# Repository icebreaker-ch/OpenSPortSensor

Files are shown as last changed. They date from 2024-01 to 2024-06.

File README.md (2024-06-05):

# Welcome to OpenSPortSensor
Telemetry for *FrSky* RC Receivers using the **SPort** interface.

The main goals for this project were:
- Provide a software easy to adapt for your own sensors by implementing a simple interface
- Support different *Arduino* boards by using high level libraries for communication only
- Support Hardware- and Software-Serial interfaces
- Supply a set of standard sensors for e.g. voltage and current measurement

The Documentation for this project can be found in the [wiki](https://github.com/icebreaker-ch/OpenSPortSensor/wiki)

<p align="center">
  <table>
    <tr>
      <td align="center">
        <figure>
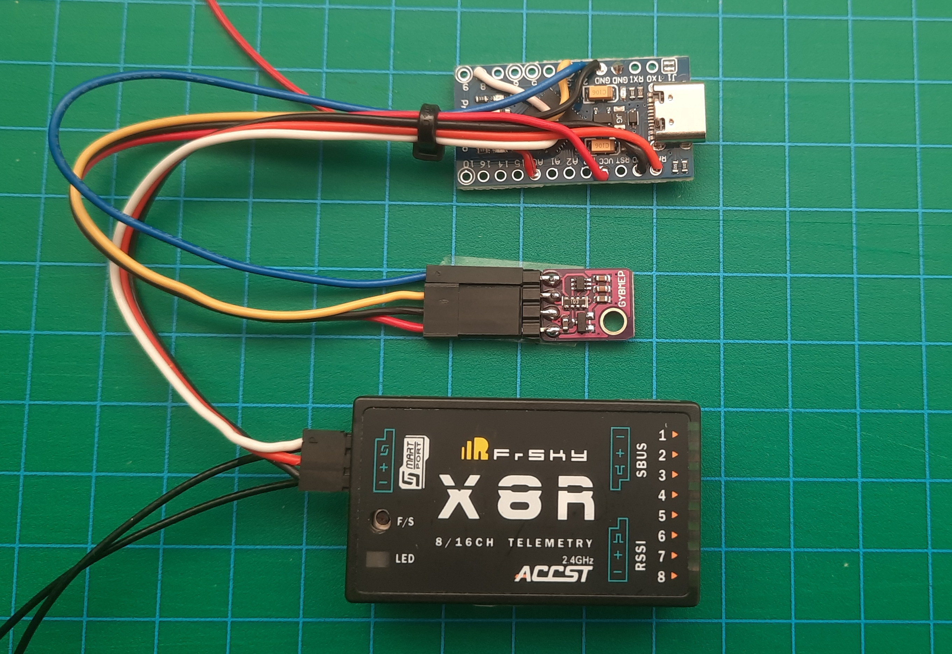
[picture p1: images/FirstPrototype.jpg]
First Prototype
          <br/>
          <figcaption>First Prototype with Voltage measuring and Vario sensor</figcaption>
        </figure>
      </td>
      <td align="center">
        <figure>
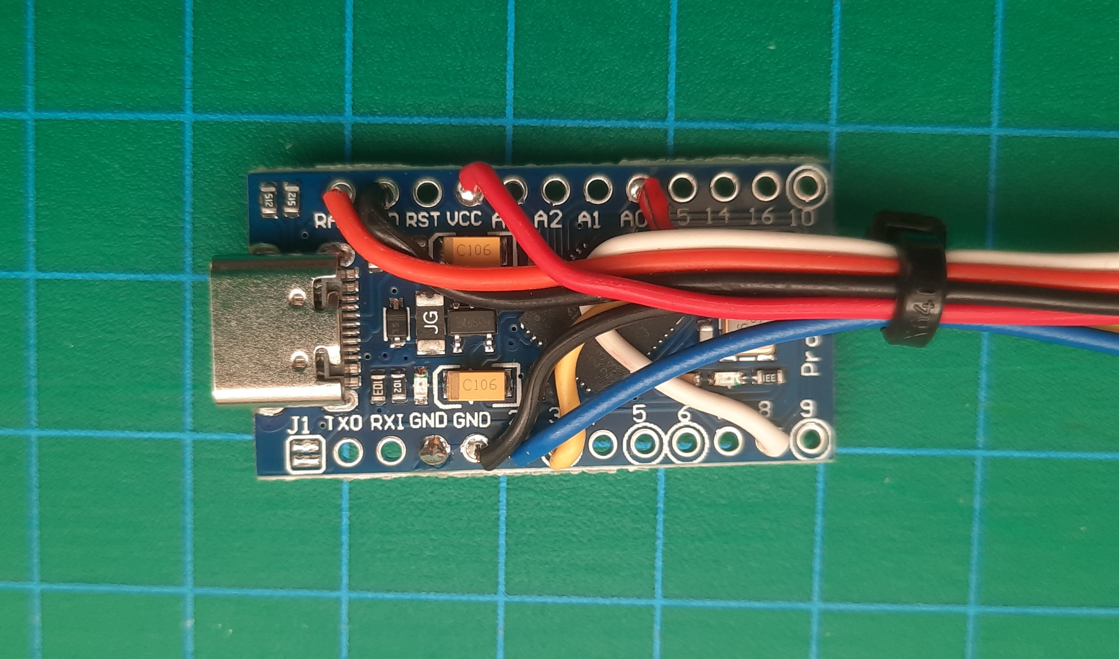
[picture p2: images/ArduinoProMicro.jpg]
Voltage and Vario Sensor with Arduino Pro Micro
          <br/>
          <figcaption>Arduino Pro Micro</figcaption>
        </figure>
        </td>
    </tr>
    <tr>
      <td align="center">
        <figure>
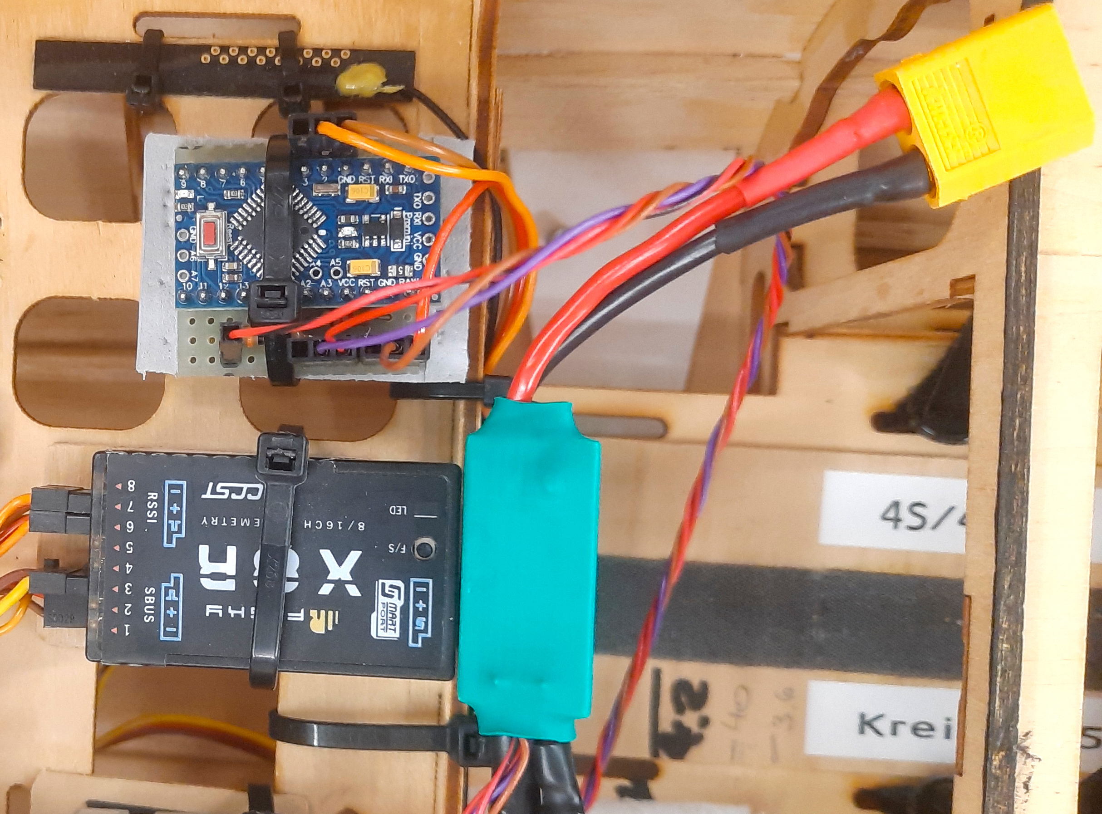
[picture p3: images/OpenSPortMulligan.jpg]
OpenSPort Sensor with current and voltage sensors in a Great Planes Mister Mulligan
          <br/>
          <figcaption>OpenSPort Sensor with current and voltage sensors in a <i>Great Planes</i> <i>Mister Mulligan<i></figcaption>
        </figure>
      </td>
    \/tr>
  </table>
</p>

[Wiring of the prototype (PDF)](https://github.com/icebreaker-ch/OpenSPortSensor/blob/main/images/ExampleConfiguration.pdf) with Voltage and Vario Sensor, using a BME280.

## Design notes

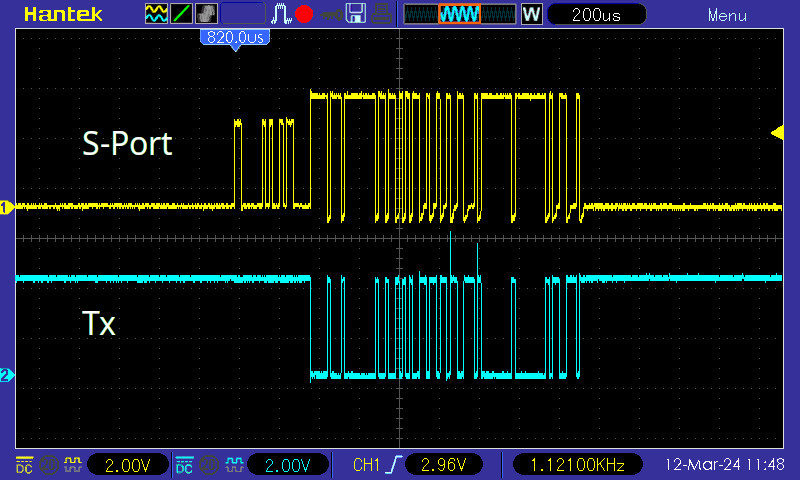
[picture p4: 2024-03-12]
images/Signals-74HC00.jpg

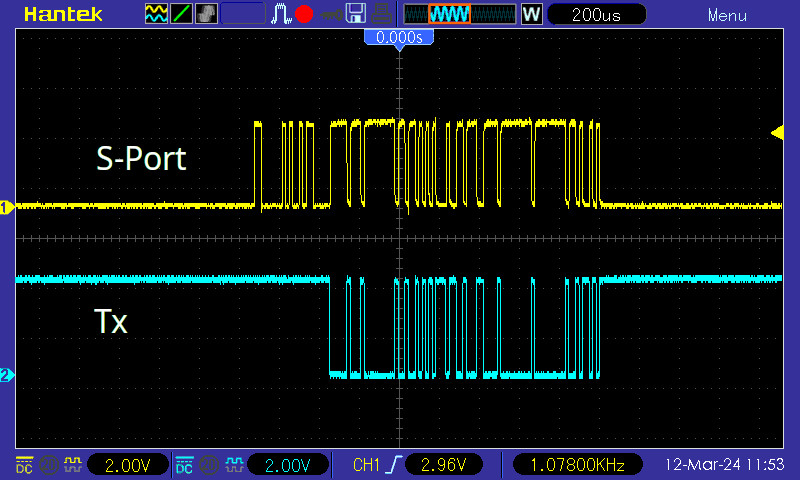
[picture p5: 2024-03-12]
images/Signals-Transistor.jpg

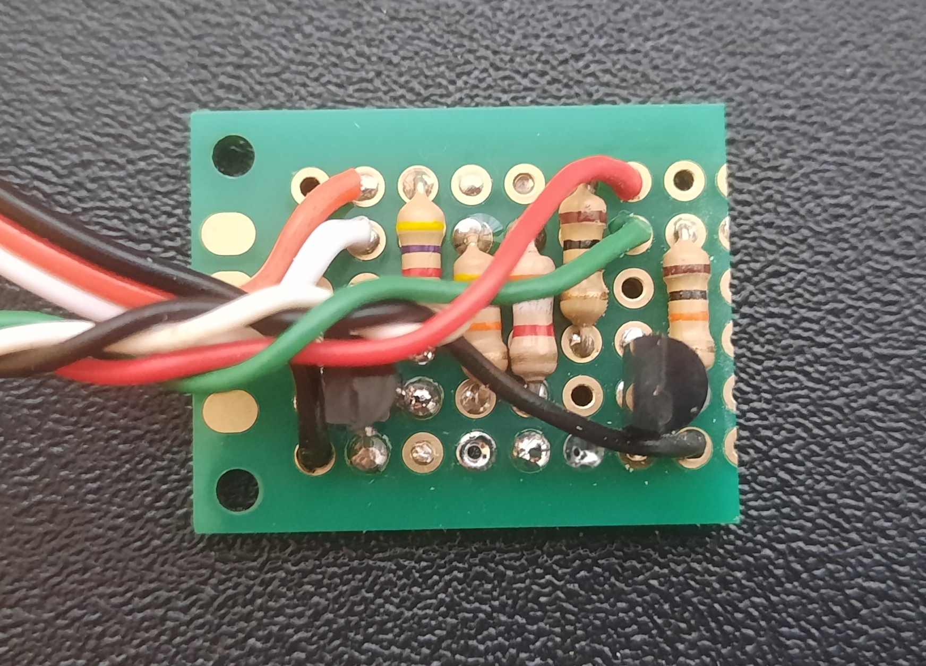
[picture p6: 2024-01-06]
images/RS232-Inverter.jpg

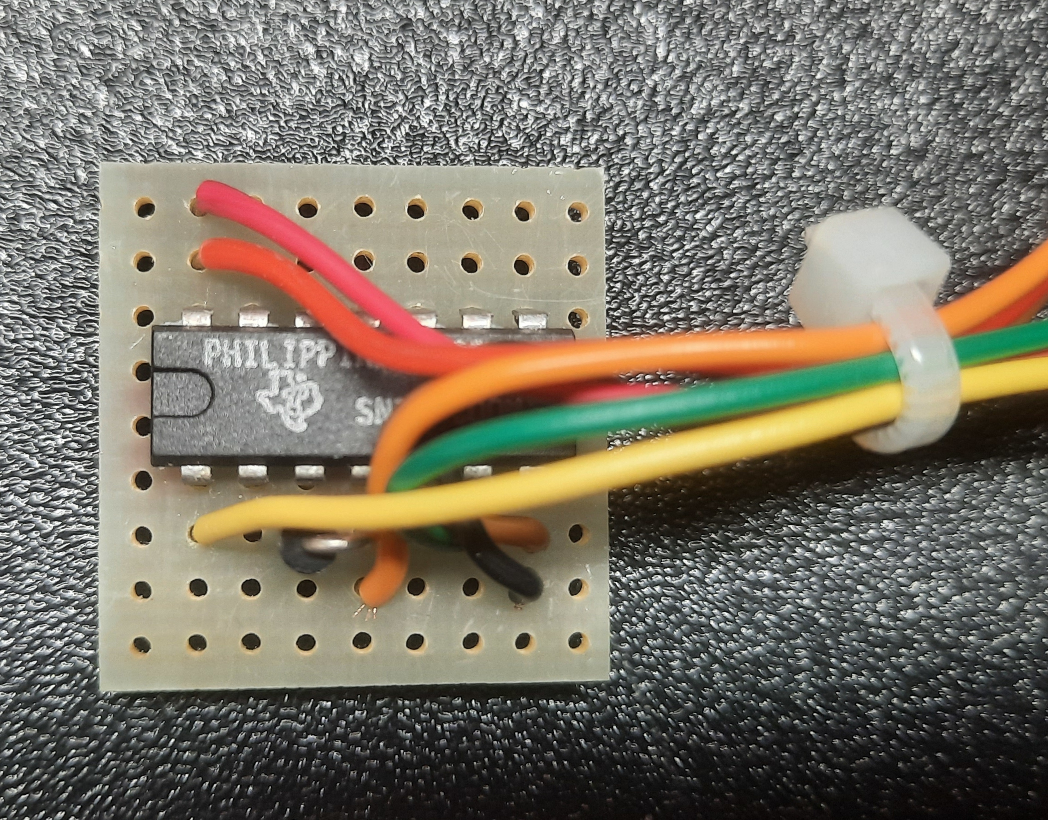
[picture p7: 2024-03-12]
images/Inverter-74HC00.jpg

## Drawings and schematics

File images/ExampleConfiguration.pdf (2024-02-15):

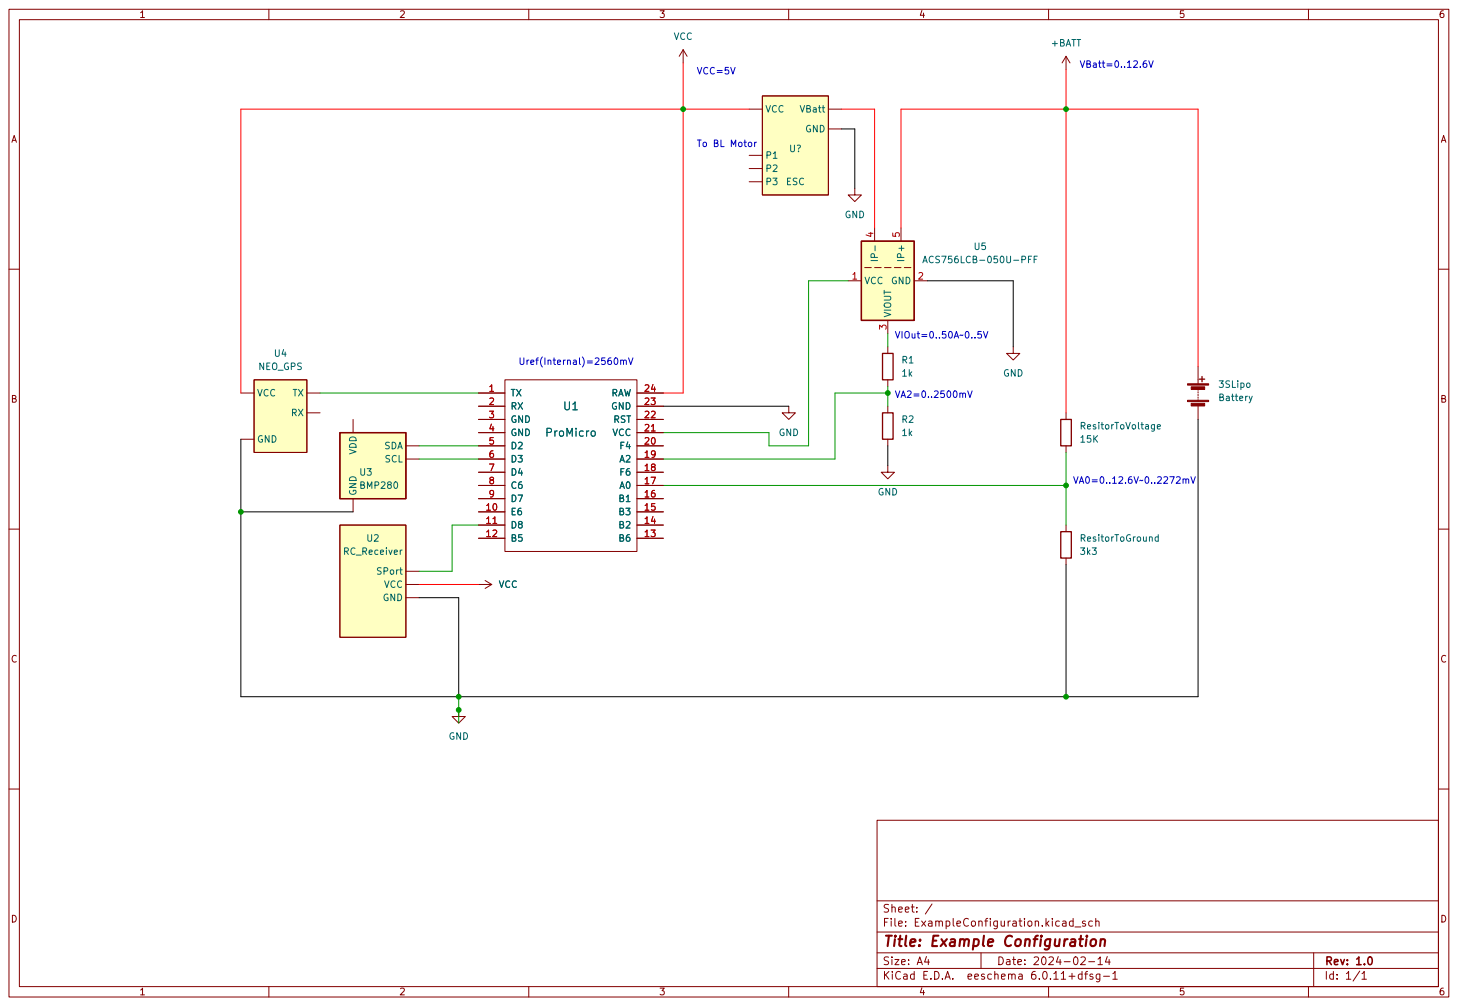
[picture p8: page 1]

Id: 1/1 Title: Example Configuration

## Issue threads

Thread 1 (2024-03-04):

Build issues

bulldog5046, 2024-03-04:
Hi,

This looks interesting but i haven't been able to get it to build successfully. Seems to be related to the included List.h but I've failed to identify what the issue is.

```In file included from src/main.cpp:6:
src/SensorHub.h:20:9: error: 'List' does not name a type; did you mean 'xList'?
         List<Sensor *> sensors;
         ^~~~
         xList
src/SensorHub.h:21:9: error: 'List' does not name a type; did you mean 'xList'?
         List<Sensor *>::Iterator iterator;
         ^~~~
         xList```

icebreaker-ch, 2024-03-04:
Hi @bulldog5046,
Thank you for your interest and the report,
Unfortunately, I can not reproduce your problem here.
Seems, that the template class List from `lib/list/src/List.h` is hidden/covered somehow in your environment.
In the meantime, I fixed another bug, preventing compilation for other environments as the _sparkfun pro micro_.
But this bug concerned the Hardware Serial for the GPS Sensor.
Are you using VS Code and PlatformIO as IDE?
For which hardware did you compile the code (`sparkfun_promicro16`, `nanoarmega328new` etc.)
On which Platform are you working (Linux, Windows...)

bulldog5046, 2024-03-05:
I believe this may be specific to using the Arduino framework with the ESP32 and a conflict with the espressif library.

I found my way here after trying a few other libraries and discovering they seem to have issues with serial timing so was looking at alternatives. Although i'm unsure where the problem really lies as i've constructed a proof-of-concept so i can accurately control the serial timing and I still find that the receiver requests updates frequently, and the same static response is given the updates on the transmitter are sporadic at best.

Have you observed this? or do you see constant updates flow like with the native receiver battery level for example? Or do you maybe have any other insights you could share?

icebreaker-ch, 2024-03-05:
I also tried, to include support for the ESP32 board, but came to the conclusion, that the differences between the EPS32 and the Atmel Atmega processors are too big. To really have a support for such different CPU architectures, you have to insert a lot of conditional compiling statements (#ifdef) into the code, which i didn't want.
The second problem with the ESP32 boards is, that they have a **3.3V logic**, so you have to put a level converter, at least between the RC Receiver (5V or more) and the ESP32.
The third problem with ESP32 is, that **Software Serial is not easy supported** (you need an external Library for doing that). To connect them to a Receiver (3 Pins and inverted logic), you need the described RS232 Inverter.
The ESP32 board is quite **bigger** than the Atmel boards, if you have little space in your model.
And finally: Do not forget, to **switch of WiFi** on the ESP32. You don't want to have another 2.4GHz transmitter in your Model.
Conclusion:
My favorite board (and the one, that is best tested with the code) is the Sparkfun Pro Micro, but an Arduino Nano 328 or Arduino Pro Mini may also be good choices.

bulldog5046, 2024-03-05:
Thanks for the response.

My scope is showing the S.Port bus to be 3.3v on the Tandem R10 i have here. You had me double checking wondering if i'd gone crazy.

Software serial does seem rubbish, but we have 3 hardware serial lines that support inversion. Like i said, i have a PoC working just trying to understand why i get such odd intermittancy issues. There looks to be a 320us delay after the Rx sends the polling until it appears to switch to listening for a response. I've artifically added this delay in to make sure we went the response at the correct time but still the Tx only updates sporadically.

The serial lines on the ESP32 look very clean on the scope so i'm not sure it's a pure signalling issue anymore. I did try someome elses library on a Mega 2560 and the serial line looked like a disaster. I reverted back to the ESP32 when i discovered this.

There is also Fbus now which is faster. I'm wondering if this could be used for telemetry?

Sorry, i've gone way off-topic from your project but just wanted to bounce some ideas around.

bulldog5046, 2024-03-05:
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

Excuse the poor screenshot, i only have a basic scope.

icebreaker-ch, 2024-03-05:
As you see in my code, I  took no measures, considering timing for communication with the Receiver (see the state machine in main.cpp and had no problems in Tx updates.
I also did not check the timing with a scope.
My be, there is indeed a need to wait some time after the polling request. The ESP32 has a CPU-clock much higher than the Atmega CPU's and therefore, the timing my be correct coincidentally in my setup. The protocol descriptions are not very detailed considering timing :-(
Check also, if your PoC program does not send 0x7D or 0x7E bytes back to the receiver (see SPortWriter.cpp) in my code. These bytes have to be encoded in 2-byte sequences.

bulldog5046, 2024-03-05:
Thanks. Indeed i did ensure to take care of the 7d/7e cases.

Just one last question, are my expectations correct that you should see updates on the transmitter at high frequency like the builtin sensors? Partially wondering if its just that external sensors don't update at the same frequency.

icebreaker-ch, 2024-03-05:
Don't know, if the update rate of external and internal sensors is the same or not.
I tended to slow down the update rate by adding filters (MeanValueFilter.cpp) to the sensors to avoid flipping values on each update.
A special case seems to be, if you have only one physical ID connected. Original text from https://github.com/Hwurzburg/FrskyTelemetryScript/wiki/FrSky-SPort-protocol-specs:

_The receiver will poll the IDs in sequence to find which one is present. If only one physical ID is found, the receiver will alternate the sensor polling and the search (present sensor, next ID to search, present sensor, next ID and so on). If more sensors are found, the poll sequence returns almost to a normal search pattern._

Will try to make some measurements of the timing behavior with my scope...

bulldog5046, 2024-03-13:
That's interesting. But also it looks like your logic isn't inverted? or are you doing something externally to invert?

icebreaker-ch, 2024-03-13:
These are the signals on the RX/TX pins of the Arduino. The Atmega chips can not do a inversion on the Hardware-Serial ports.  I used an Inverter between S-Port and RX/TX,
More details and diagrams [in the wiki](https://github.com/icebreaker-ch/OpenSPortSensor/wiki/Software--vs.-Hardware-Serial)

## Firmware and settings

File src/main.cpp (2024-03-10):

#include <Arduino.h>
#include <TxData.h>
#include <List.h>
#include "log.h"
#include "config.h"
#include "SensorHub.h"
#include "Sensor.h"
#include "TestSensor.h"
#include "VoltageSensor.h"
#include "CurrentSensor.h"
#include "BME280.h"
#include "AltitudeSensor.h"
#include "VerticalSpeedSensor.h"
#ifdef GPS_SENSOR
#include "NeoGPSSensor.h"
#include "GPSCourseSensor.h"
#include "GPSPositionSensor.h"
#include "GPSAltitudeSensor.h"
#include "GPSSpeedSensor.h"
#endif
#include "IPollingDevice.h"
#include "NullFilter.h"
#include "MeanValueFilter.h"
#include "SPortHardwareStream.h"
#include "SPortSoftwareStream.h"
#include "SPortWriter.h"

#define START_BYTE 0x7E

#ifdef USE_HARDWARE_SERIAL
static ISPortStream *pStream = new SPortHardwareStream();
#else
static ISPortStream *pStream = new SPortSoftwareStream(SOFTWARE_SERIAL_PIN);
#endif

static SPortWriter *pSPortWriter;
static SensorHub hub(PHYSICAL_ID);
static List<IPollingDevice *> pollingDevices;

static void addSensors() {
#ifdef TEST_SENSOR
    // Add required sensors here
    // Test Sensor
    // ===========
    TestSensor *pTestSensor = new TestSensor(0x5200);
    hub.addSensor(pTestSensor);
#endif

#ifdef VOLTAGE_SENSOR
    // Voltage Sensor
    // ==============
    VoltageSensor *pVoltageSensor = new VoltageSensor(A0, 15000, 3300);
    pVoltageSensor->setFilter(new MeanValueFilter());
    pVoltageSensor->setReportInterval(STANDARD_INTERVAL);
    hub.addSensor(pVoltageSensor);
#endif

#ifdef CURRENT_SENSOR
    // Current Sensor
    // ==============
    CurrentSensor *pCurrentSensor = new CurrentSensor(A2, 1280.0, 25.0);
    pCurrentSensor->setFilter(new MeanValueFilter());
    pCurrentSensor->setReportInterval(STANDARD_INTERVAL);
    hub.addSensor(pCurrentSensor);
#endif

#ifdef VARIO_SENSOR
    // Vario
    // =====
    // Vario: Altitude
    IAltitudeSensor *pBme280 = new BME280();
    AltiudeSensor *pAltSensor = new AltiudeSensor(pBme280);
    pAltSensor->setFilter(new MeanValueFilter());
    pAltSensor->setReportInterval(STANDARD_INTERVAL);
    hub.addSensor(pAltSensor);
    // Vario: Vertical speed
    VerticalSpeedSensor *pVerticalSpeedSensor = new VerticalSpeedSensor(pBme280);
    pVerticalSpeedSensor->setFilter(new MeanValueFilter());
    pVerticalSpeedSensor->setReportInterval(STANDARD_INTERVAL);
    hub.addSensor(pVerticalSpeedSensor);
#endif

 #ifdef GPS_SENSOR
    // GPS
    NeoGPSSensor *pNeoGPSSensor = new NeoGPSSensor();
    pollingDevices.add(pNeoGPSSensor); // register as polling device for feeding GPS data
    // GPS: Position Sensor
    GPSPositionSensor *pLatitudeLongitudeSensor = new GPSPositionSensor(pNeoGPSSensor);
    hub.addSensor(pLatitudeLongitudeSensor);

    // GPS: Altitude Sensor
    GPSAltitudeSensor *pGPSAltitudeSensor = new GPSAltitudeSensor(pNeoGPSSensor);
    hub.addSensor(pGPSAltitudeSensor);

    // GPS: Speed Sensor
    GPSSpeedSensor *pGPSSpeedSensor = new GPSSpeedSensor(pNeoGPSSensor);
    hub.addSensor(pGPSSpeedSensor);

    // GPS: Course Sensor
    GPSCourseSensor *pGPSCourseSensor = new GPSCourseSensor(pNeoGPSSensor);
    hub.addSensor(pGPSCourseSensor);
#endif
}

void setup() {
#ifdef LOGGING_ON
    Serial.begin(9600); // For debugging output
#endif

    pinMode(LED_PIN, OUTPUT);
    analogReference(ANALOG_REFERENCE);
    addSensors();

    pStream->begin(S_PORT_BAUD, SERIAL_8N1);
    pStream->listen();

    pSPortWriter = new SPortWriter(pStream);
}

enum State {
    stateWaitHeader,
    stateWaitPhysicalId,
    stateWriteData
};

static State state = stateWaitHeader;

void loop() {
    unsigned char byte;

    // Hanlde polling devices in every loop
    for (List<IPollingDevice *>::Iterator it = pollingDevices.begin(); it != pollingDevices.end(); ++it) {
        (*it)->poll();
    }

    switch (state) {
    case stateWaitHeader:
        digitalWrite(LED_PIN, HIGH);
        if ((pStream->available() && (pStream->readBytes(&byte, 1) == 1) && (byte == START_BYTE))) {
            state = stateWaitPhysicalId;
        }
        break;

    case stateWaitPhysicalId:
        if ((pStream->available() && (pStream->readBytes(&byte, 1) == 1) && (byte == hub.getPhysicalId()))) {
            state = stateWriteData;
        }
        break;

    case stateWriteData:
        digitalWrite(LED_PIN, LOW);

        pStream->stopListening();
        Sensor *pSensor = hub.getNextSensor();
        unsigned char bytes[TxData::LEN];
        TxData data(pSensor->getSensorId(), pSensor->getValue());
        data.getData(bytes);
        pSPortWriter->write(bytes, TxData::LEN);

        pStream->listen();
        state = stateWaitHeader;
        break;
    }
}

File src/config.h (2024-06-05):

#ifndef CONFIG_H
#define CONFIG_H

#include "global.h"

/**
 * Define this, if you want to embed the Test Sensor
*/
//#define TEST_SENSOR

/**
 * Define this, if you want to embed a Voltage Sensor
*/
#define VOLTAGE_SENSOR

/**
 * Define this, if you want to embed a Current Sensor
*/
#define CURRENT_SENSOR

/**
 * Define this, if you want to embed a GPS Sensor
*/
#define GPS_SENSOR

/**
 * Define this, if you want to embed a Vario Sensor
*/
#define VARIO_SENSOR

/**
 * Uncomment this, if you want to use the Hardware Serial interface (RX/TX Pins)
 * on your board to handle the communication between the Arduino and the Receiver.
 * You need a RS232 Inverter Board between the Arduino and the Receiver.
 */
//#define USE_HARDWARE_SERIAL

#ifndef USE_HARDWARE_SERIAL
/**
 * Defines the pin to be used for SoftrwareSerial communication to the S.Port of the Receiver.
 * No additional Hardware is required, when you use SoftwareSerial.
 */
#define SOFTWARE_SERIAL_PIN 8
#endif

/**
 * Defines the baud rate for the S.Port communication. The default is 57600
 * which should be fine.
 */
#define S_PORT_BAUD 57600

/**
 * Number of milliseconds for sensor timeout
 */
#define SENSOR_TIMEOUT 10000

/**
 * Define the Physical ID of the Hub
 * Choose one of the defined IDs which is not used by another sensor in your system.
 */
#define PHYSICAL_ID PHYSICAL_ID11

/**
 * The standard interval in mS to report new values
 */
#define STANDARD_INTERVAL 500L

/**
 * Define, what to use as the analog reference voltage.
 * can be one of:
 * - DEFAULT: the default analog reference of 5 volts (on 5V Arduino boards) or 3.3 volts (on 3.3V Arduino boards)
 * - INTERNAL: a built-in reference, equal to 1.1 volts on the ATmega168 or ATmega328P and 2.56 volts on the ATmega32U4 and ATmega8 (not available on the Arduino Mega)
 * - INTERNAL1V1: a built-in 1.1V reference (Arduino Mega only)
 * - INTERNAL2V56: a built-in 2.56V reference (Arduino Mega only)
 * - EXTERNAL: the voltage applied to the AREF pin (0 to 5V only) is used as the reference.
 */
#define ANALOG_REFERENCE INTERNAL

/**
 * Defines the reference voltage in [mV]
 * Use:
 * - INTERNAL_REFERENCE_VOLTAGE if you want to use the internal reference voltage of e.g. 1.1, or 2.56 V, depending of the board
 * - The specific voltage, applied to AREF pin if you want to use an EXTERNAL analog reference voltage
 * - The specific voltage of VCC if you want to use the DEFAULT analog reference.
 */
#define ANALOG_REFERENCE_VOLTAGE INTERNAL_REFERENCE_VOLTAGE

#endif

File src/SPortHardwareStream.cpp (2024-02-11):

#include "SPortHardwareStream.h"

SPortHardwareStream::SPortHardwareStream() :
    serial(HARDWARE_SERIAL_STREAM) {
}

void SPortHardwareStream::begin(unsigned long speed, byte config) {
    serial.begin(speed, config);
}

void SPortHardwareStream::listen() {
    // Not necessary for hardware serial
}

void SPortHardwareStream::stopListening() {
    // Not necessary for hardware serial
}

int SPortHardwareStream::available() {
    return serial.available();
}

int SPortHardwareStream::read() {
    return serial.read();
}

size_t SPortHardwareStream::write(uint8_t c) {
    return serial.write(c);
}

int SPortHardwareStream::peek() {
    return serial.peek();
}

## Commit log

2024-01-04 Updated the board informations
2024-01-04 Added support for different boards
2024-01-04 Voltage sensor added
2024-01-06 Added a BME280 Altitude Sensor
2024-01-08 Moved SimpleSensor to sensors directory
2024-01-08 Added BME280 Vario Sensor
2024-01-09 Added Filter interface and MeanValueFilter
2024-01-10 Enhanced Filter usage
2024-01-10 Added unit tests and completed Vario Sensor
2024-01-12 Avoid multiple instances of terminating printLog
2024-01-12 Moved max sensors for hub to config
2024-01-13 Minor enhncements and configuration for first prototype sensor
2024-01-13 First prototype
2024-01-14 Filters for all sensors
2024-01-14 Bugfix Voltage Sensor
2024-02-01 Renamed Interval to Timer
2024-02-01 Simplified Timer
2024-02-02 Added NullFilter and made filter mandatory
2024-02-02 Flash LED in main loop
2024-02-04 First steps implementing a GPS Sensor
2024-02-05 First working GPS Sensor
2024-02-08 Added more GPS Sensors
2024-02-08 Added Course Sensor
2024-02-10 Fixed include in conditional compilation
    [SPortSoftwareStream.cpp]
2024-02-10 Added CurrentSensor
2024-02-11 Added current sensor to drawing
2024-02-12 Voltage divider for current sensor
2024-02-14 Changed schema to KiCAD
    [ExampleConfiguration.kicad_sch]
2024-02-15 Added Labels with voltage values
    [ExampleConfiguration.kicad_sch]
2024-03-04 Fixed problem for non arduino pro micro platforms considering Serial1
2024-03-05 Find configuration problem for HardwareSerial
    [config.h]
2024-06-05 Clarified usage of reference voltage config
